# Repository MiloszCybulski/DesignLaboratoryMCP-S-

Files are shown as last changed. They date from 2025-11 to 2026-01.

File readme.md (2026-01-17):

# Design Laboratory — MCP-S

Repozytorium projektu realizowanego w ramach przedmiotu **Design Laboratory (2025/26)**.  
Celem projektu jest zaprojektowanie i uruchomienie układu elektronicznego wraz z oprogramowaniem (m.in. obsługa wyświetlacza 7-segmentowego oraz rozszerzeń czujnikowych), a także zebranie dokumentacji technicznej.

Autorzy:
- Paweł Ścibek
- Sylwester Ślusarczyk
- Miłosz Cybulski

Dokumentację końcową projektu można znaleźć pod następującym linkiem: [Dokumentacja projektu](https://docs.google.com/document/d/1e8B4XN3sytEK4NsDrXsqLLuhZmmhayYSinMeYGpmRww/edit?tab=t.0)

## Instrukcje

Kod źródłowy do płytki AVR znajduje się w pliku `code/avr_final.c`.

Aby uruchomić aplikację, należy wykonać poniższą komendę trzeba z katalogu root projektu wykonać:

``` bash
cd code/
```
A nastepnie komendę: 

```bash
python3 AVR_Interface.py
```

## ENG Version

Repository for the project conducted as part of the **Design Laboratory (2025/26)** course.  
The goal of the project is to design and implement an electronic system along with software (including 7-segment display handling and sensor extensions), as well as to compile technical documentation.

Authors:
- Paweł Ścibek
- Sylwester Ślusarczyk
- Miłosz Cybulski

The final project documentation can be found at the following link: [Project Documentation](https://docs.google.com/document/d/1e8B4XN3sytEK4NsDrXsqLLuhZmmhayYSinMeYGpmRww/edit?tab=t.0)

## Instructions

The source code for the AVR board can be found in the file `code/avr_final.c`.

To run the application, execute the following command from the root directory of the project:

``` bash
cd code/
```
Then, run the command:
``` bash
python3 AVR_Interface.py
```

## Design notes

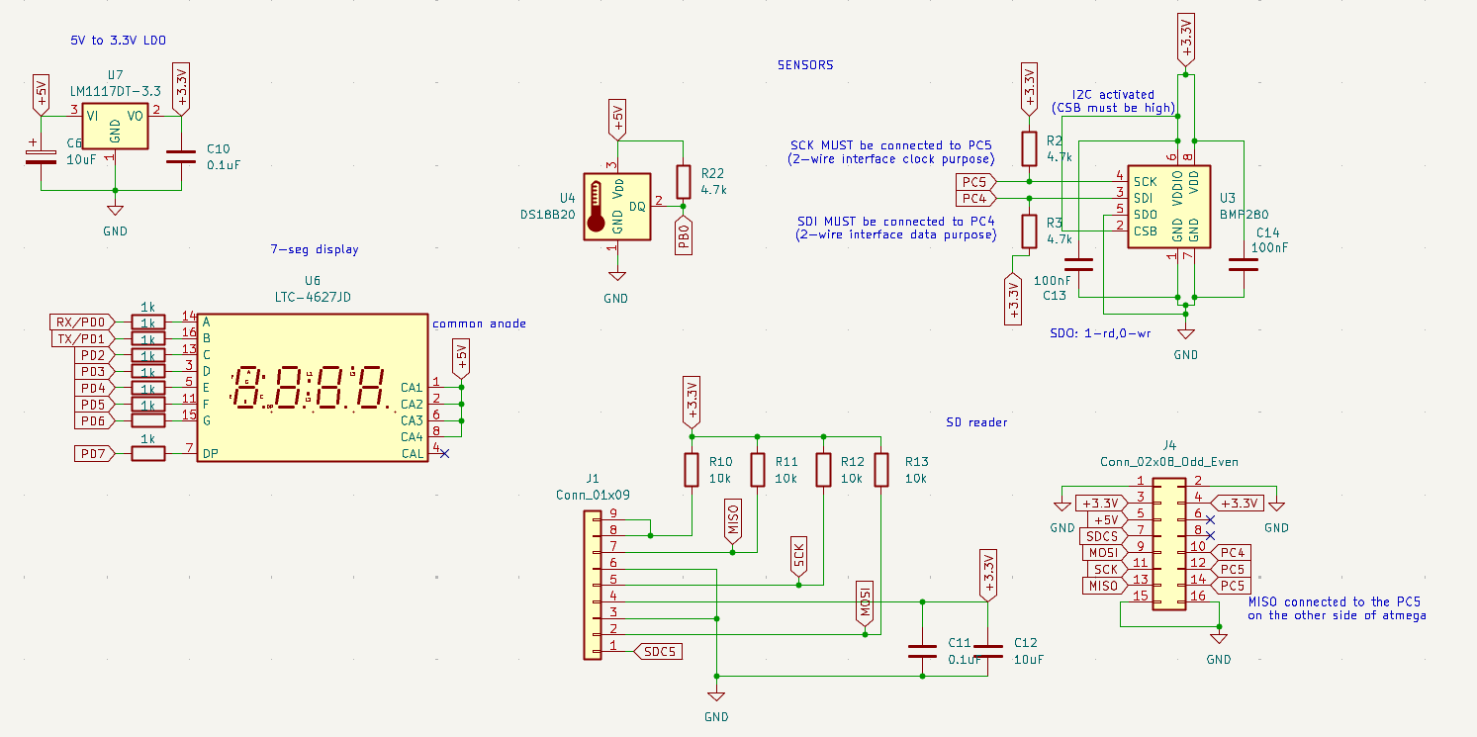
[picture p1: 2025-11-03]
sensors_&_new_functionalities.png

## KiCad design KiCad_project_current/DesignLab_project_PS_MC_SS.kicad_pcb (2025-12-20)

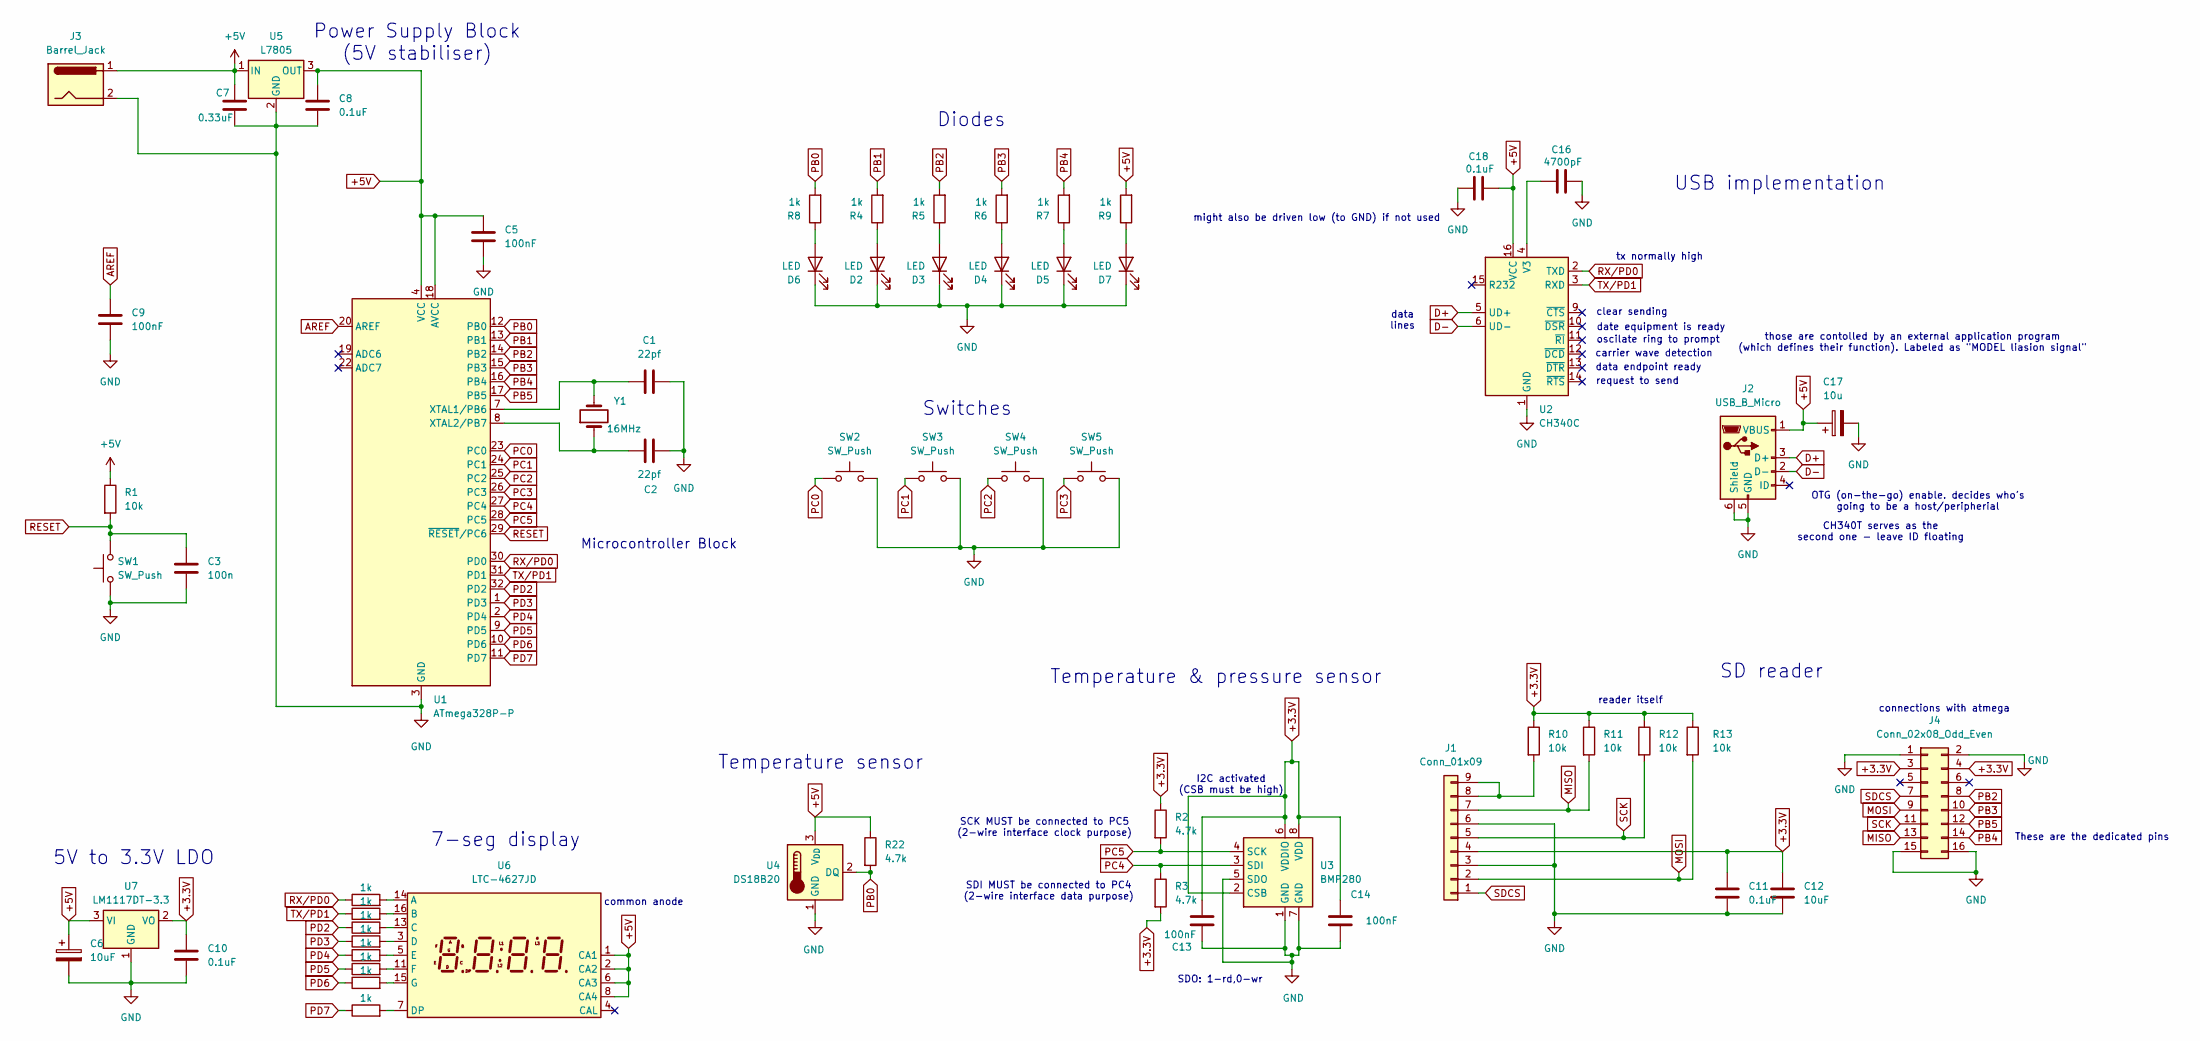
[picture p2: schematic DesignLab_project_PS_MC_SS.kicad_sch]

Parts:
C1, C2: 22pf; C_0603_1608Metric
C3: 100n; C_0603_1608Metric
C5, C9, C13, C14: 100nF; C_0603_1608Metric
C6: 10uF; CP_Elec_4x3
C7: 0.33uF; C_0603_1608Metric
C8, C10, C11, C18: 0.1uF; C_0603_1608Metric
C12: 10uF; C_0603_1608Metric
C16: 4700pF; C_0603_1608Metric
C17: 10u; CP_Elec_4x3
D2, D3, D4, D5, D6, D7: LED; LED_0603_1608Metric
J1: Conn_01x09; PinHeader_1x09_P2.54mm_Vertical
J2: USB_B_Micro; USB_Micro-B_Molex-105017-0001
J3: Barrel_Jack; BarrelJack_Horizontal
J4: Conn_02x08_Odd_Even; PinHeader_2x08_P2.54mm_Vertical
R1, R10, R11, R12, R13: 10k; R_0805_2012Metric_Pad1.20x1.40mm_HandSolder
R2, R3, R22: 4.7k; R_0805_2012Metric_Pad1.20x1.40mm_HandSolder
R4, R5, R6, R7, R8, R9, R14, R15, R16, R17, R18, R19, R20, R21: 1k; R_0805_2012Metric_Pad1.20x1.40mm_HandSolder
SW1, SW2, SW3, SW4, SW5: SW_Push; SW_Tactile_SPST_NO_Straight_CK_PTS636Sx25SMTRLFS
U1: ATmega328P-P; TQFP-32_7x7mm_P0.8mm
U2: CH340C; SOIC-16_3.9x9.9mm_P1.27mm
U3: BMP280; Bosch_LGA-8_2x2.5mm_P0.65mm_ClockwisePinNumbering
U4: DS18B20; TO-92_Inline
U5: L7805; TO-252-2
U6: LTC-4627JD; LTC-4627Jx
U7: LM1117DT-3.3; TO-252-3_TabPin2
Y1: 16MHz; Oscillator_SMD_Abracon_ASDMB-4Pin_2.5x2.0mm

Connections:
+3.3V: C10.1, C11.1, C12.1, C13.2, C14.1, J1.4, J4.3, J4.4, R2.1, R3.2, R10.1, R11.1, R12.1, R13.1, U3.2 (CSB), U3.6 (VDDIO), U3.8 (VDD), U7.2 (VO)
+5V: C5.1, C6.1, C7.1, C8.1, C17.1, C18.2, J2.1 (VBUS), J3.1, R1.1, R9.2, R22.1, U1.4 (VCC), U1.6 (VCC), U1.18 (AVCC), U2.16 (VCC), U4.3 (V_{DD}), U5.1 (IN), U5.3 (OUT), U6.1 (CA1), U6.2 (CA2), U6.6 (CA3), U6.8 (CA4), U7.3 (VI)
AREF: C9.1, U1.20 (AREF)
D+: J2.3 (D+), U2.5 (UD+)
D-: J2.2 (D-), U2.6 (UD-)
GND: C1.2, C2.2, C3.2, C5.2, C6.2, C7.2, C8.2, C9.2, C10.2, C11.2, C12.2, C13.1, C14.2, C16.2, C17.2, C18.1, D2.1 (K), D3.1 (K), D4.1 (K), D5.1 (K), D6.1 (K), D7.1 (K), J1.3, J1.6, J2.5 (GND), J2.6 (Shield), J3.2, J4.1, J4.2, J4.15, J4.16, SW1.1, SW2.2, SW3.2, SW4.2, SW5.2, U1.3 (GND), U1.5 (GND), U1.21 (GND), U2.1 (GND), U3.1 (GND), U3.5 (SDO), U3.7 (GND), U4.1 (GND), U5.2 (GND), U7.1 (GND)
MISO: J1.7, J4.13, R11.2
MOSI: J1.2, J4.9, R13.2
unnamed: D2.2 (A), R4.1
unnamed: D3.2 (A), R5.1
unnamed: D4.2 (A), R6.1
unnamed: D5.2 (A), R7.1
unnamed: D6.2 (A), R8.1
unnamed: D7.2 (A), R9.1
unnamed: J1.8, J1.9, R10.2
unnamed: C1.1, U1.7 (XTAL1/PB6), Y1.2
unnamed: C2.1, U1.8 (XTAL2/PB7), Y1.1
unnamed: C16.1, U2.4 (V3)
unnamed: R14.2, U6.14 (A)
unnamed: R15.2, U6.16 (B)
unnamed: R16.2, U6.13 (C)
unnamed: R17.2, U6.3 (D)
unnamed: R21.2, U6.7 (DP)
unnamed: R18.2, U6.5 (E)
unnamed: R19.2, U6.11 (F)
unnamed: R20.2, U6.15 (G)
PB0: R8.2, R22.2, U1.12 (PB0), U4.2 (DQ)
PB1: R4.2, U1.13 (PB1)
PB2: J4.8, R5.2, U1.14 (PB2)
PB3: J4.10, R6.2, U1.15 (PB3)
PB4: J4.14, R7.2, U1.16 (PB4)
PB5: J4.12, U1.17 (PB5)
PC0: SW2.1, U1.23 (PC0)
PC1: SW3.1, U1.24 (PC1)
PC2: SW4.1, U1.25 (PC2)
PC3: SW5.1, U1.26 (PC3)
PC4: R3.1, U1.27 (PC4), U3.3 (SDI)
PC5: R2.2, U1.28 (PC5), U3.4 (SCK)
PD2: R16.1, U1.32 (PD2)
PD3: R17.1, U1.1 (PD3)
PD4: R18.1, U1.2 (PD4)
PD5: R19.1, U1.9 (PD5)
PD6: R20.1, U1.10 (PD6)
PD7: R21.1, U1.11 (PD7)
RESET: C3.1, R1.2, SW1.2, U1.29 (~RESET/PC6)
RX/PD0: R14.1, U1.30 (PD0), U2.2 (TXD)
SCK: J1.5, J4.11, R12.2
SDCS: J1.1, J4.7
TX/PD1: R15.1, U1.31 (PD1), U2.3 (RXD)

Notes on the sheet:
USB implementation
data endpoint ready
Diodes
clear sending
SDI MUST be connected to PC4 (2-wire interface data purpose)
Power Supply Block (5V stabiliser)
Switches
connections with atmega
SD reader
data lines
tx normally high
common anode
5V to 3.3V LDO
7-seg display
Temperature & pressure sensor
oscilate ring to prompt
request to send
Temperature sensor
might also be driven low (to GND) if not used
Microcontroller Block
These are the dedicated pins
SCK MUST be connected to PC5 (2-wire interface clock purpose)
SDO: 1-rd,0-wr
OTG (on-the-go) enable. decides who's going to be a host/peripherial
reader itself
those are contolled by an external application program (which defines their function). Labeled as "MODEL liasion signal"
CH340T serves as the second one - leave ID floating
date equipment is ready
carrier wave detection
I2C activated (CSB must be high)

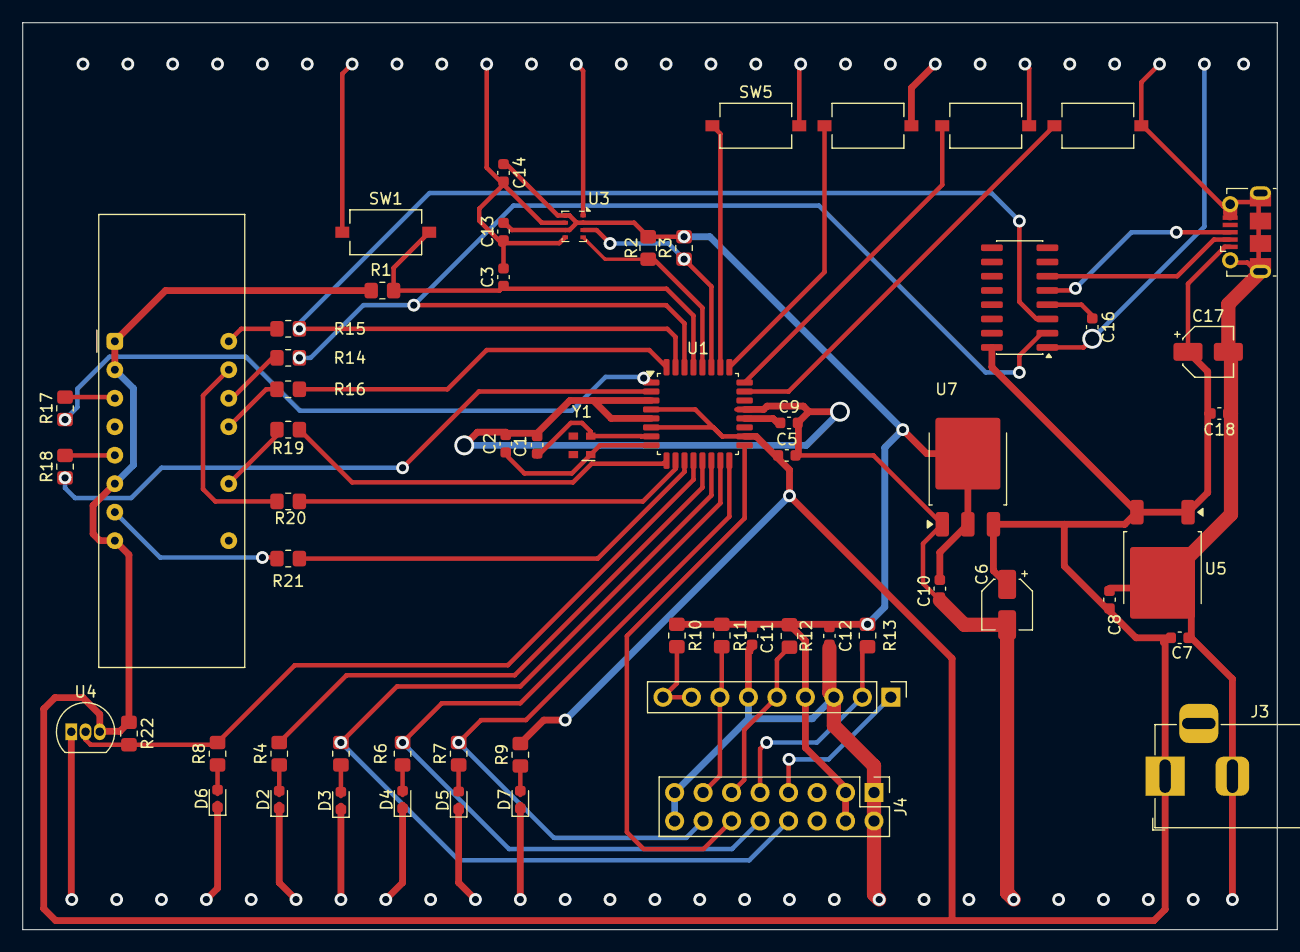
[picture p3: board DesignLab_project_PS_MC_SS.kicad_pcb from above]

Board: 2 copper layers, 111.9 x 80.9 mm, 61 parts (0 on the bottom side), 49 nets.

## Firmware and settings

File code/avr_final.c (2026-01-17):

#define F_CPU 16000000UL

#include <avr/io.h>
#include <util/delay.h>
#include <stdint.h>
#include <stdio.h>
#include <avr/interrupt.h>


/* ============================================================
   UART – Asynchronous Serial Communication
   Used for diagnostics, user commands, and sensor readout.
   ============================================================ */

int32_t rT, rP;

void led_update(uint8_t active);
void uart_puts(const char *s);



void uart_init()
{
    // Baud rate 9600 (UBRR = 103 for 16 MHz)
    UBRR0H = 0;
    UBRR0L = 103;

    UCSR0B = (1<<TXEN0)|(1<<RXEN0)|(1<<RXCIE0); 

    UCSR0C = (1<<UCSZ01)|(1<<UCSZ00);
}

char uart_read()
{
	return UDR0;
}

static volatile uint8_t choosenTEMP = 0;
static volatile uint8_t choosenPRESSURE = 0;
static volatile uint8_t choosenTEMPds18b20 = 0;
static volatile uint8_t choosenLEDON = 0;
static volatile uint8_t choosenLEDOFF = 0;
static volatile uint8_t choosenRESET = 0;


ISR(USART0_RX_vect)
{
	char c = uart_read();
	
	switch(c)
	{
		case 't':
		choosenTEMP = 1;
		break;
		case 'p':
		choosenPRESSURE = 1;
		break;
		case 's':
		choosenTEMPds18b20 = 1;
		break;
		case 'd':
		choosenLEDON = 1;
		break;
		case 'a':
		choosenLEDOFF = 1;
		break;
		case 'r':
		choosenRESET = 1;
		break;
	}
	
}


void uart_putc(char c)
{
	uint8_t timeout = 0;
	while (!(UCSR0A & (1<<UDRE0)) && timeout < 100) 
	{
		_delay_us(10);  
		timeout++;
	}
	if (timeout < 100) {
		UDR0 = c;
	}
	else {
		uart_puts("UART Timeout Error\r\n");
	}
}

void uart_puts(const char *s)
{
    while (*s) uart_putc(*s++);
}

uint8_t uart_available()
{
    return (UCSR0A & (1<<RXC0));
}


/* ============================================================
   I²C (TWI) – Communication with BMP/QMP Sensor
   ============================================================ */

#define TWCR TWCR0
#define TWBR TWBR0
#define TWSR TWSR0
#define TWDR TWDR0

void i2c_init()
{
    TWSR = 0;     
    TWBR = 72;   
}

void i2c_start()
{
    TWCR = (1<<TWINT)|(1<<TWSTA)|(1<<TWEN);
    while (!(TWCR & (1<<TWINT)));
}

void i2c_stop()
{
    TWCR = (1<<TWINT)|(1<<TWEN)|(1<<TWSTO);
}

void i2c_write(uint8_t data)
{
    TWDR = data;
    TWCR = (1<<TWINT)|(1<<TWEN);
    while (!(TWCR & (1<<TWINT)));
}

uint8_t i2c_read_ack()
{
    TWCR = (1<<TWINT)|(1<<TWEN)|(1<<TWEA);
    while (!(TWCR & (1<<TWINT)));
    return TWDR;
}

uint8_t i2c_read_nack()
{
    TWCR = (1<<TWINT)|(1<<TWEN);
    while (!(TWCR & (1<<TWINT)));
    return TWDR;
}

/* ============================================================
   BMP Sensor – Initialization and Raw Data Readout
   ============================================================ */

#define SENSOR_ADDR 0x76

void sensor_init()
{
    // Control register: temperature + pressure oversampling
    i2c_start();
    i2c_write(SENSOR_ADDR<<1);
    i2c_write(0xF4);
    i2c_write(0x27);
    i2c_stop();

    // Config register
    i2c_start();
    i2c_write(SENSOR_ADDR<<1);
    i2c_write(0xF5);
    i2c_write(0x00);
    i2c_stop();
}

void sensor_read_raw(int32_t *rawT, int32_t *rawP)
{
    uint8_t d[6];

    i2c_start();
    i2c_write(SENSOR_ADDR<<1);
    i2c_write(0xF7); // first data register
    i2c_start();
    i2c_write((SENSOR_ADDR<<1)|1);

    for (uint8_t i=0;i<5;i++) d[i] = i2c_read_ack();
    d[5] = i2c_read_nack();
    i2c_stop();

    *rawP = ((int32_t)d[0]<<12) | ((int32_t)d[1]<<4) | (d[2]>>4);
    *rawT = ((int32_t)d[3]<<12) | ((int32_t)d[4]<<4) | (d[5]>>4);
}

/* ============================================================
   BMP Calibration – Simplified Scaling Model
   ============================================================ */

float T_scale  = 0.0007801f;
float T_offset = -394.5f;

int32_t temp_times100(int32_t rawT)
{
    float T = rawT * T_scale + T_offset;
    return (int32_t)(T * 100.0f);
}

float P_scale  = 0.2506f;
float P_offset = 0.0f;

int32_t press_pa(int32_t rawP)
{
    float P = rawP * P_scale + P_offset;
    return (int32_t)P;
}

/* ============================================================
   LED – Simple GPIO Indicator
   ============================================================ */

#define LED_PORT PORTC
#define LED_DDR  DDRC
#define LED_PIN  PC3

void led_init()
{
    LED_DDR |= (1<<LED_PIN);
    LED_PORT &= ~(1<<LED_PIN);
}

void led_update(uint8_t active)
{
    if (active) LED_PORT |= (1<<LED_PIN);
    else LED_PORT &= ~(1<<LED_PIN);
}

/* ============================================================
   DS18B20 – Full 1-Wire Implementation
   ============================================================ */

#define DS_PORT PORTC
#define DS_PIN  PC4
#define DS_DDR  DDRC
#define DS_PINREG PINC

static inline void ds_output() { DS_DDR |= (1<<DS_PIN); }
static inline void ds_input()  { DS_DDR &= ~(1<<DS_PIN); }

uint8_t ds_reset()
{
    ds_output();
    DS_PORT &= ~(1<<DS_PIN);
    _delay_us(480);

    ds_input();
    _delay_us(70);

    uint8_t presence = !(DS_PINREG & (1<<DS_PIN));

    _delay_us(410);
    return presence;
}

void ds_write_bit(uint8_t bit)
{
    ds_output();
    DS_PORT &= ~(1<<DS_PIN);
    _delay_us(2);

    if (bit) ds_input();
    _delay_us(60);

    ds_input();
}

uint8_t ds_read_bit()
{
    uint8_t bit;

    ds_output();
    DS_PORT &= ~(1<<DS_PIN);
    _delay_us(2);

    ds_input();
    _delay_us(10);

    bit = (DS_PINREG & (1<<DS_PIN)) ? 1 : 0;

    _delay_us(50);
    return bit;
}

void ds_write_byte(uint8_t data)
{
    for (uint8_t i=0;i<8;i++)
    {
        ds_write_bit(data & 1);
        data >>= 1;
    }
}

uint8_t ds_read_byte()
{
    uint8_t data = 0;

    for (uint8_t i=0;i<8;i++)
    {
        data >>= 1;
        if (ds_read_bit()) data |= 0x80;
    }
    return data;
}

int16_t ds_read_temperature()
{
    if (!ds_reset()) return 0;

    ds_write_byte(0xCC); // SKIP ROM
    ds_write_byte(0x44); // CONVERT T

    _delay_ms(750);

    ds_reset();
    ds_write_byte(0xCC);
    ds_write_byte(0xBE);

    uint8_t tempL = ds_read_byte();
    uint8_t tempH = ds_read_byte();

    int16_t raw = (tempH << 8) | tempL;

    float tempC = raw * 0.0625f;
    return (int16_t)(tempC * 100);
}

/* ============================================================
   7-Segment Display – Common Cathode, Multiplexed
   ============================================================ */

#define SEG_PORTB PORTB
#define SEG_DDRB  DDRB
#define SEG_PORTD PORTD
#define SEG_DDRD  DDRD

#define DIG_PORTC PORTC
#define DIG_DDRC  DDRC
#define DIG_PORTB PORTB
#define DIG_DDRB  DDRB

#define DIG1 PC1
#define DIG2 PC0
#define DIG3 PC2
#define DIG4 PB5

// Your verified segment map (common cathode)
const uint8_t segment_map[10] = {
    0b00001100, // 0
    0b10011111, // 1
    0b01001010, // 2
    0b00001011, // 3
    0b10011001, // 4
    0b00101001, // 5
    0b00101000, // 6
    0b10001111, // 7
    0b00001000, // 8
    0b00001001  // 9
};

void seg_init()
{
    SEG_DDRB |= 0x0F;
    SEG_DDRD |= 0xF0;

    DIG_DDRC |= (1<<DIG1)|(1<<DIG2)|(1<<DIG3);
    DIG_DDRB |= (1<<DIG4);

    SEG_PORTB |= 0x0F;
    SEG_PORTD |= 0xF0;

    DIG_PORTC |= (1<<DIG1)|(1<<DIG2)|(1<<DIG3);
    DIG_PORTB |= (1<<DIG4);
}

void seg_set_digit(uint8_t digit)
{
    SEG_PORTD = (SEG_PORTD & ~0xF0) | (digit & 0xF0);
    SEG_PORTB = (SEG_PORTB & ~0x0F) | (digit & 0x0F);
}

void seg_enable(uint8_t d)
{
    DIG_PORTC |= (1<<DIG1)|(1<<DIG2)|(1<<DIG3);
    DIG_PORTB |= (1<<DIG4);

    if (d==1) DIG_PORTC &= ~(1<<DIG1);
    if (d==2) DIG_PORTC &= ~(1<<DIG2);
    if (d==3) DIG_PORTC &= ~(1<<DIG3);
    if (d==4) DIG_PORTB &= ~(1<<DIG4);
}

void seg_show_4digits_once(int16_t value)
{
    uint8_t d4 = (value/1000)%10;
    uint8_t d3 = (value/100)%10;
    uint8_t d2 = (value/10)%10;
    uint8_t d1 = (value/1)%10;

    seg_set_digit(segment_map[d4]); seg_enable(1); _delay_ms(1);
    seg_set_digit(segment_map[d3]); seg_enable(2); _delay_ms(1);
    seg_set_digit(segment_map[d2]); seg_enable(3); _delay_ms(1);
    seg_set_digit(segment_map[d1]); seg_enable(4); _delay_ms(1);
}

/* ============================================================
   MAIN – System Logic
   ============================================================ */

int main()
{
    uart_init();
	uart_puts("Starting I2C communication...\r\n");
	i2c_init();
	uart_puts("Sensor initialized.\r\n");
    
    led_init();
    seg_init();
    sensor_init();
	sei();  


    uart_puts("=== SYSTEM READY ===\r\n");
    uart_puts("Available commands:\r\n");
    uart_puts(" t - read temperature (BMP/QMP)\r\n");
    uart_puts(" p - read pressure\r\n");
    uart_puts(" s - read temperature (DS18B20)\r\n");
    uart_puts(" d - LED ON\r\n");
    uart_puts(" a - LED OFF\r\n");
    uart_puts(" r - reset message\r\n");
    uart_puts("====================\r\n");



     while (1)
     {
			if (choosenTEMP)
			{
				sensor_read_raw(&rT,&rP);
				int32_t T = temp_times100(rT);

				char buf[32];
				sprintf(buf,"BMP Temp: %ld.%02ld C\r\n",T/100,T%100);
				uart_puts(buf);
				choosenTEMP = 0;
			}

			if (choosenPRESSURE)
			{
				sensor_read_raw(&rT,&rP);
				int32_t P = press_pa(rP);

				char buf[32];
				sprintf(buf,"Pressure: %ld Pa\r\n",P);
				uart_puts(buf);
				choosenPRESSURE = 0;
			}

			if (choosenTEMPds18b20)
			{
				int16_t t = ds_read_temperature();
				char buf[32];
				sprintf(buf,"DS18B20: %d.%02d C\r\n", t/100, abs(t%100));
				uart_puts(buf);
				choosenTEMPds18b20 = 0;
			}

			if (choosenLEDON)
			{
				led_update(1);
				uart_puts("LED ON\r\n");
				choosenLEDON = 0;
			}

			if (choosenLEDOFF)
			{
				led_update(0);
				uart_puts("LED OFF\r\n");
				choosenLEDOFF = 0;
			}

			if (choosenRESET)
			{
				uart_puts("RESET OK\r\n");
				uart_puts("\r\n");
				uart_puts("=== SYSTEM READY ===\r\n");
				uart_puts("Available commands:\r\n");
				uart_puts(" t - read temperature (BMP/QMP)\r\n");
				uart_puts(" p - read pressure\r\n");
				uart_puts(" s - read temperature (DS18B20)\r\n");
				uart_puts(" d - LED ON\r\n");
				uart_puts(" a - LED OFF\r\n");
				uart_puts(" r - reset message\r\n");
				uart_puts("====================\r\n");
				choosenRESET = 0;
			}
		}

		// Display temperature from BMP on 7-seg
		sensor_read_raw(&rT,&rP);
		int32_t T = temp_times100(rT);

		seg_show_4digits_once(T);
		_delay_ms(100);  
}

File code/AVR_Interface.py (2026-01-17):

from tkinter import *
from tkinter.scrolledtext import ScrolledText
import serial

s = serial.Serial('/dev/ttyUSB0', 9600, timeout=1)
root = Tk()
root.title("UART-data visualization")

frame = Frame(root)
frame.pack(padx=10, pady=10)

log = ScrolledText(
    frame,
    width=60,
    height=15,
    font=("Consolas", 11)
)
log.pack(fill="both", expand=True)

led_canvas = Canvas(root, width=40, height=40, highlightthickness=0)
led_canvas.pack(padx=10, pady=10)
led_id = led_canvas.create_oval(5, 5, 35, 35, fill="gray20", outline="gray50")
led_on = False 
led_label = Label(root, text="LED", font=("Arial", 12))
led_label.pack(pady=2)

buttons = Frame(root)
buttons.pack(side="top", fill="x", padx=10, pady=5)

## LED ### 
def set_led(state: bool) -> None:
    """Ustawia kolor diody."""
    color = "lime green" if state else "gray20"
    led_canvas.itemconfig(led_id, fill=color)

### Tx ### 
def send_uart(cmd):
    s.write((cmd + "\n").encode("utf-8"))
    log.insert("end", f">>> {cmd}\n")
    log.see("end")

def call_temp():
    send_uart("t")

def call_psi():
    send_uart("p")

def call_led_on(state: bool) -> None:
    send_uart("d")
    global led_on
    led_on = state
    set_led(led_on)

def call_led_off(state: bool) -> None:
    send_uart("a")
    global led_on
    led_on = state
    set_led(led_on)

def call_reset():
    send_uart("r")


### BUTTONS ### 
btn_temp = Button(buttons, text="°C", command=call_temp)
btn_temp.pack(side="left", padx=5)

btn_pressure = Button(buttons, text="PSI", command=call_psi)
btn_pressure.pack(side="left", padx=5)

btn_led_on = Button(buttons, text="LED ON", command= lambda: call_led_on(True))
btn_led_on.pack(side="left", padx=5)

btn_led_off = Button(buttons, text="LED OFF", command= lambda: call_led_off(False))
btn_led_off.pack(side="left", padx=5)

btn_reset = Button(buttons, text="RESET", command=call_reset)
btn_reset.pack(side="left", padx=5)

### Rx ### 
def read_uart():
    while s.in_waiting:
        line = s.readline().decode("utf-8", errors="ignore")
        line = line.replace("\r\n", "\n").replace("\r", "\n")
        if line:
            log.insert("end", line)
            log.see("end")  

    root.after(100, read_uart)


read_uart()
root.mainloop()














# e = Entry(root, width=20)
# e.pack()

# def myClick():
#     myLabel = Label(root, text="Hello Elo")
#     myLabel.pack()

# def myTempClick():
#     tempLabel = Label(root, text="BMP")
#     tempLabel.pack()

# myButton = Button(root, text="Click Me!", command=myClick, fg="red", bg="#000000")
# myButton.grid(row=1, column=0)



# tempButton = Button(root, text="Update Temp", command=myTempClick, fg="red", bg="#000000")
# myButton.grid(row=2, column=1)

# def button_add():
#     return

# tempButton     =  Button(root, text=" Temperature", width=10, pady=20, command=button_add)
# pressureButton =  Button(root, text="  Pressure  ", width=10, pady=20, command=button_add)
# ledOnButton    =  Button(root, text="   LED ON   ", width=10, pady=20, command=button_add)
# led0ffButton   =  Button(root, text="   LED OFF  ", width=10, pady=20, command=button_add)
# resetButton    =  Button(root, text="    RESET   ", width=10, pady=20, command=button_add)

# tempButton.grid(row=0, column=0)
# pressureButton.grid(row=1, column=0)
# ledOnButton.grid(row=2, column=0)
# led0ffButton.grid(row=3, column=0)
# resetButton.grid(row=4, column=0)

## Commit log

2025-10-27 Create koddopłytki_V1.0
    Kod do płytki zawierający sterowanie LED oraz płytką przyciskową
2025-10-27 kod do płytki V_1.5
    //próbny kod płytki LED + płytka przyciskowa + wyświetlacz 7 seg + karta sd, aktualnie kod wyświetla liczby od 0 do 9 sprawdzając działanie i połączenia wyświetlaczu 7 seg, kod do czytnika karty sd j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
2025-11-19 Create próbauarta
    próba kodowania uarta
2025-11-30 Current version of the KiCad project
    [DesignLab_project_PS_MC_SS.kicad_pcb, DesignLab_project_PS_MC_SS.kicad_sch]
2025-12-07 Current version of KiCad project
    [DesignLab_project_PS_MC_SS.kicad_pcb]
2025-12-20 Final version of the KiCad project
    [DesignLab_project_PS_MC_SS.kicad_pcb, DesignLab_project_PS_MC_SS.kicad_sch]
2026-01-17 bug fix in C code and added interface to display data
    [AVR_Interface.py]
